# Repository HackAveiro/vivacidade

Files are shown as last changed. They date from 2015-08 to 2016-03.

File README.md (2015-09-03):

Interactive LED wall
====================
This project is being developed to be installed in a public space in Aveiro that was recovered by a wide group of public and citizens entities. [vivacidade.umnovolargo.pt!](http://vivacidade.umnovolargo.pt)  
The interactive wall has 100 LEDs mounted in jam jars ! Each bottle has an RGB LED ( Neopixel ) and LDR sensor for users to physically interact with the wall. The panel is controlled by an Arduino which uses a radio link to communicate with a gateway situated a few hundred meters away and connects the system to the Internet. Because the place has no available electricity or Internet access it's powered by solar panels.  
Users can interact with the system through the Web App: [vivacidade-ledmatrixcontroller!](https://github.com/HackAveiro/vivacidade-ledmatrixcontroller)

Prototype images
===================
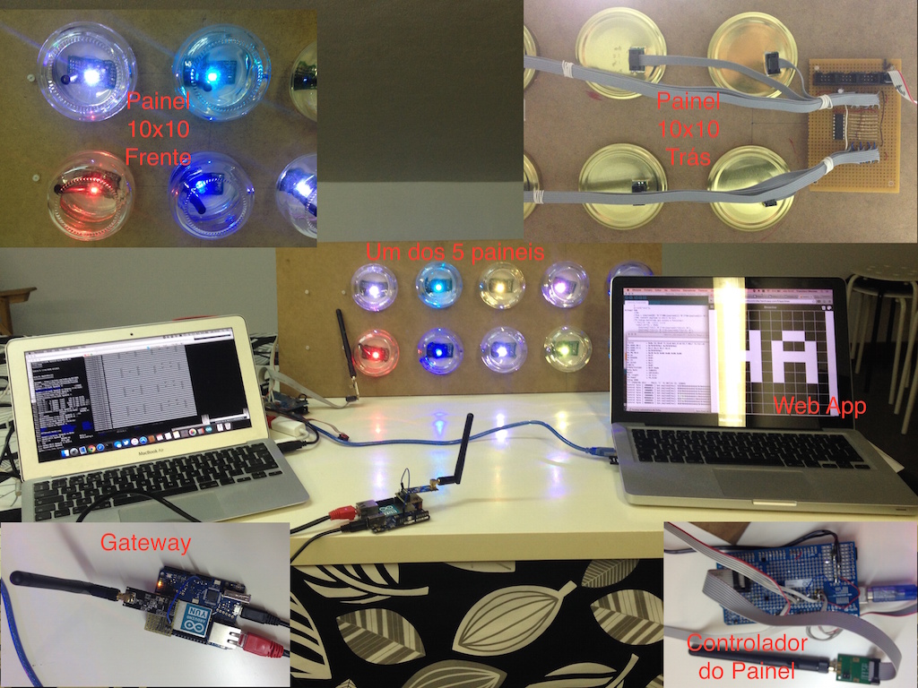
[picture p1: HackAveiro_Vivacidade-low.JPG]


GIT Structure
=============

[ADC_BOARD!](ADC_Board)
===========
The system have 10 of this boards to connect all the 100 LED. The ADC board also have ADC chips that convert the LDR light sensors readings. The ADC chips are connected to the Arduino main board via a SPI bus.
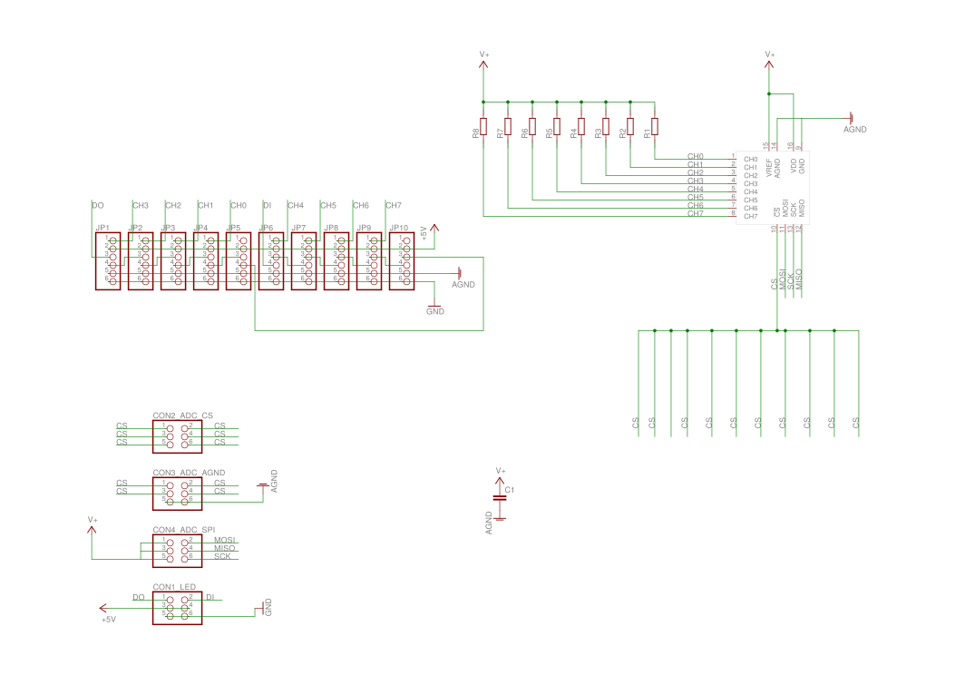
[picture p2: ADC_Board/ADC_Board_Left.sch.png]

PCB Schematic (Left Board)
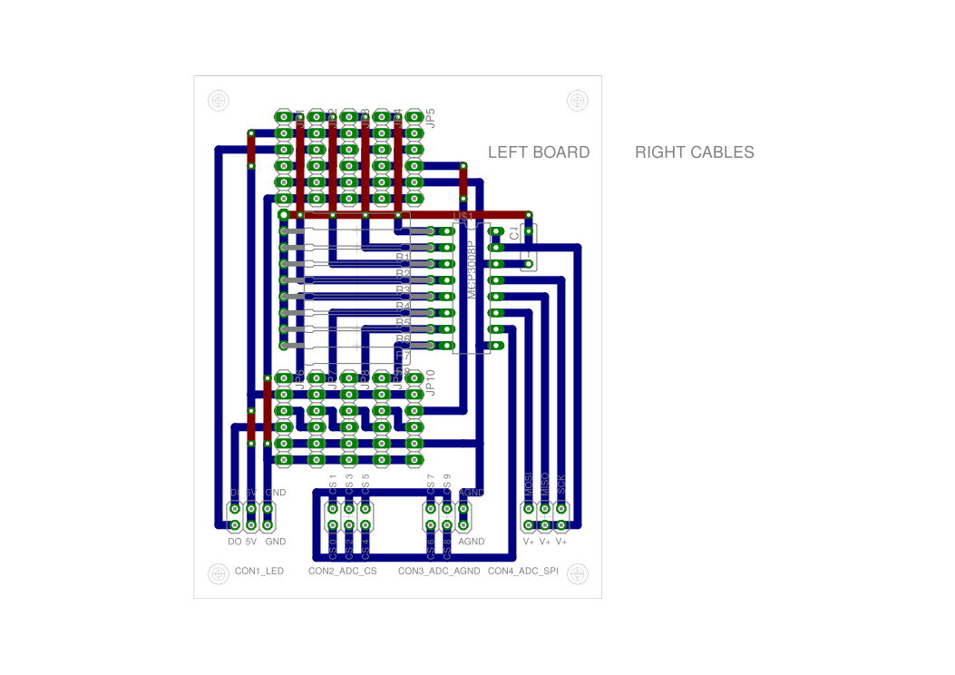
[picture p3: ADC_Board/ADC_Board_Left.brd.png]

PCB Layout ( (Left Board)
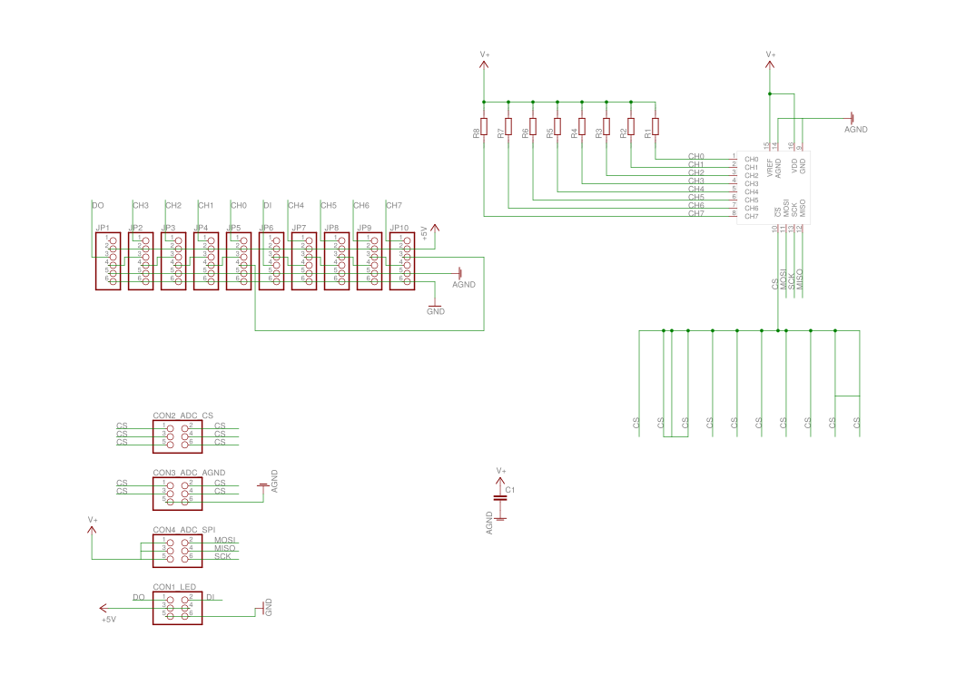
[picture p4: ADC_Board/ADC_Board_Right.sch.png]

PCB Schematic (Left Board)
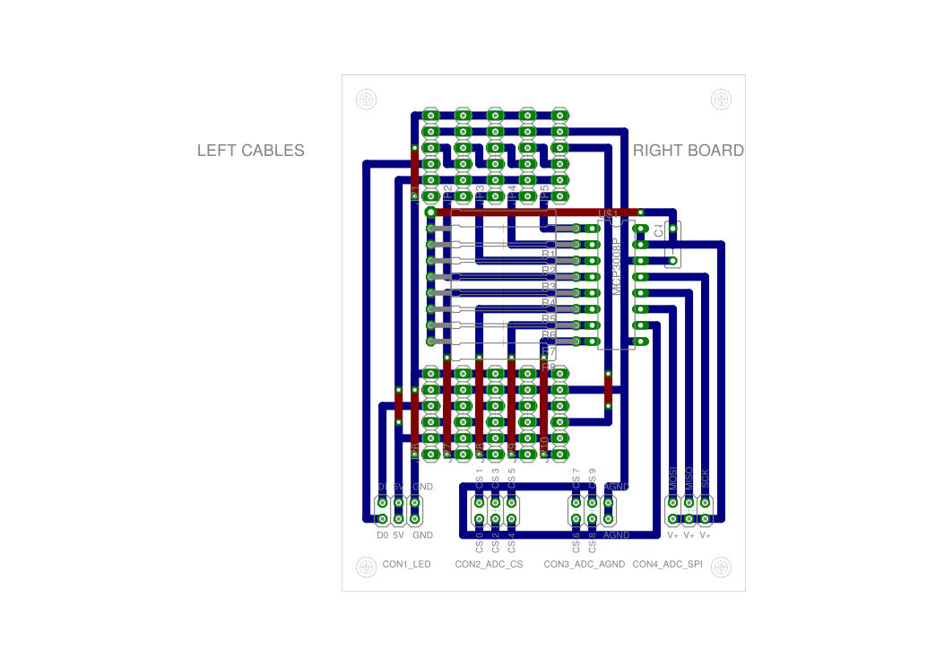
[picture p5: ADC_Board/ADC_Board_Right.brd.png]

PCB Layout ( (Left Board)

[Gateway_Vivacidade!](Gateway_Vivacidade)
==================
{{Citation needed}} 

[led_board!](led_board)
=========
{{Citation needed}} 
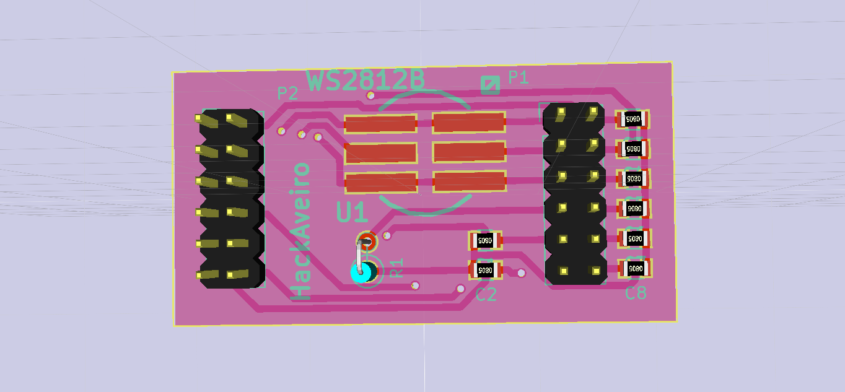
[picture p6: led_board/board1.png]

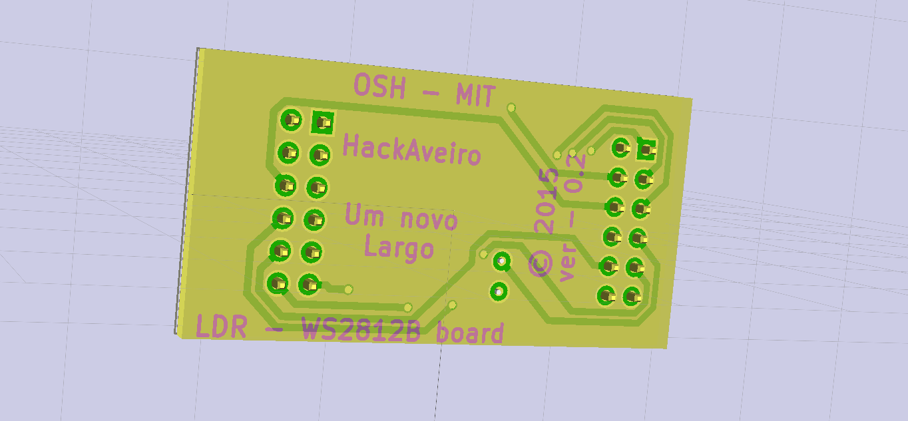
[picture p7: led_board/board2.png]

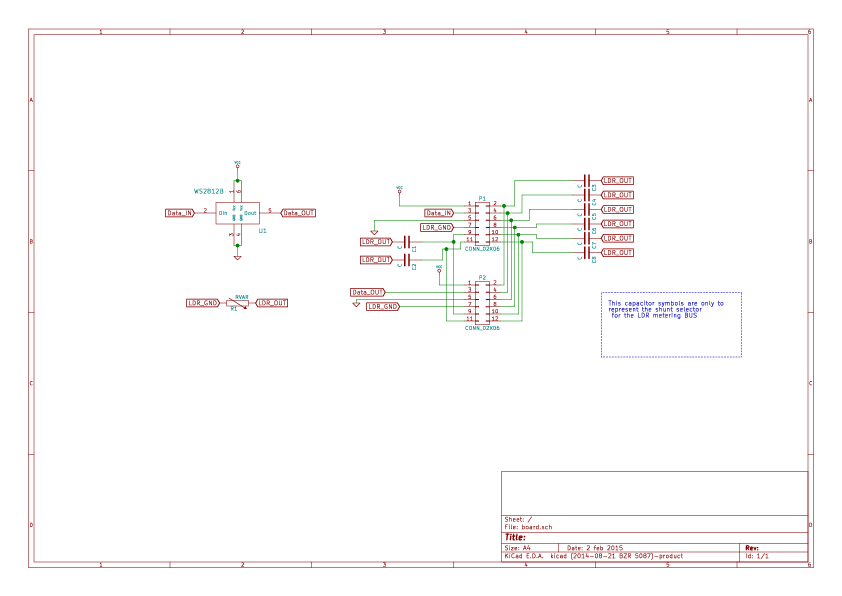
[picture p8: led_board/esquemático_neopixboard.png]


Arduino dependencies
====================
* MCP3008 - https://github.com/nodesign/MCP3008
* RF24 - https://github.com/maniacbug/RF24.git
* FastLED - https://github.com/FastLED/FastLED

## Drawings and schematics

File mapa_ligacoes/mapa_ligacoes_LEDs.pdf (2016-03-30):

# VISTA DE TRÁZ

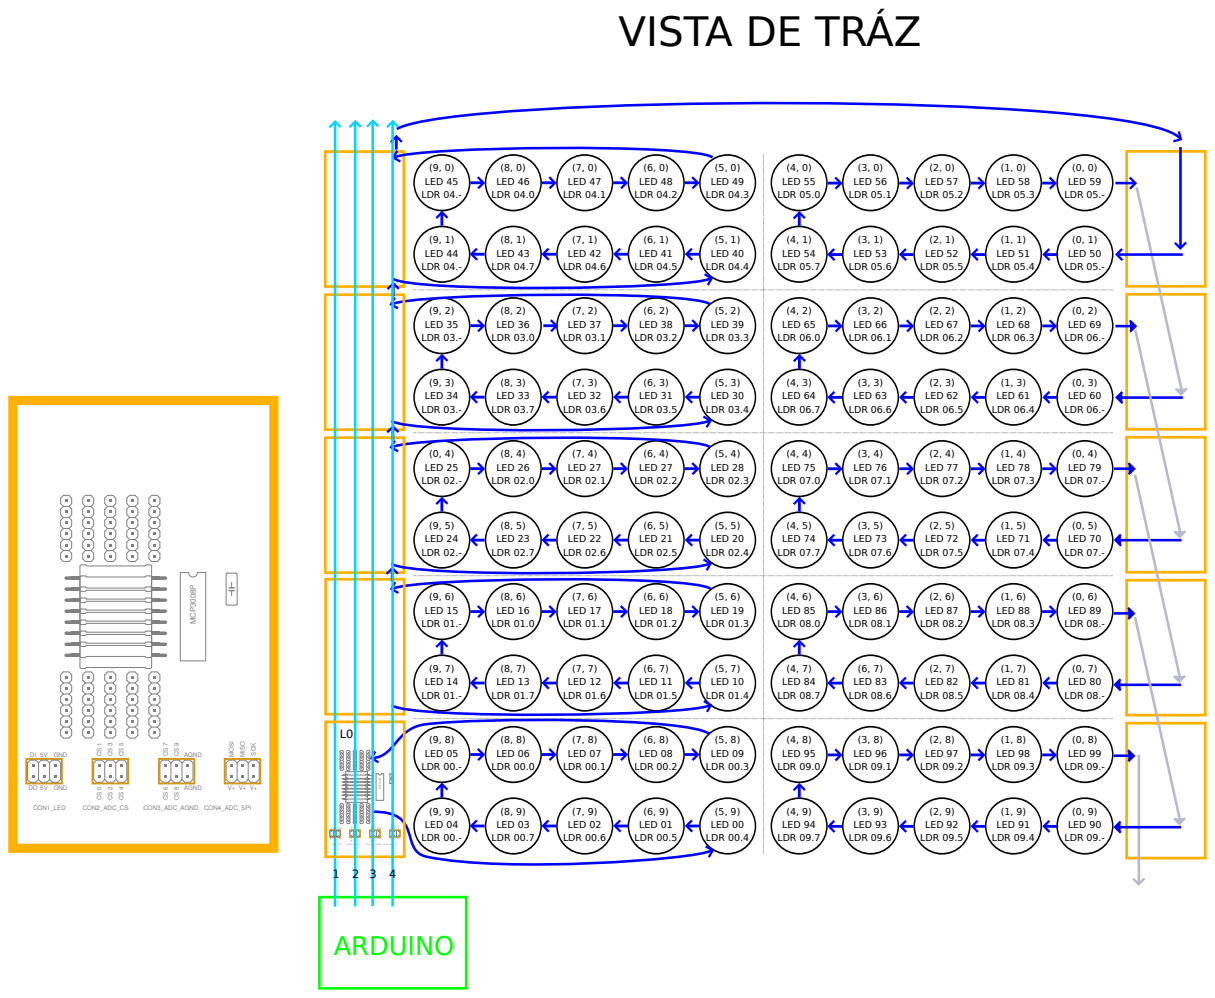
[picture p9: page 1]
(9, 9) LED 04 LDR 00.-; (0, 9) LED 90 LDR 09.-; (8, 9) LED 03 LDR 00.7; (7, 9) LED 02 LDR 00.6; (6, 9) LED 01 LDR 00.5; (5, 9) LED 00 LDR 00.4; (4, 9) LED 94 LDR 09.7; (3, 9) LED 93 LDR 09.6; (2, 9) LED 92 LDR 09.5; (1, 9) LED 91 LDR 09.4; (9, 8) LED 05 LDR 00.-; (0, 8) LED 99 LDR 09.-; (8, 8) LED 06 LDR 00.0; (7, 8) LED 07 LDR 00.1; (6, 8) LED 08 LDR 00.2; (5, 8) LED 09 LDR 00.3; (4, 8) LED 95 LDR 09.0; (3, 8) LED 96 LDR 09.1; (2, 8) LED 97 LDR 09.2; (1, 8) LED 98 LDR 09.3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

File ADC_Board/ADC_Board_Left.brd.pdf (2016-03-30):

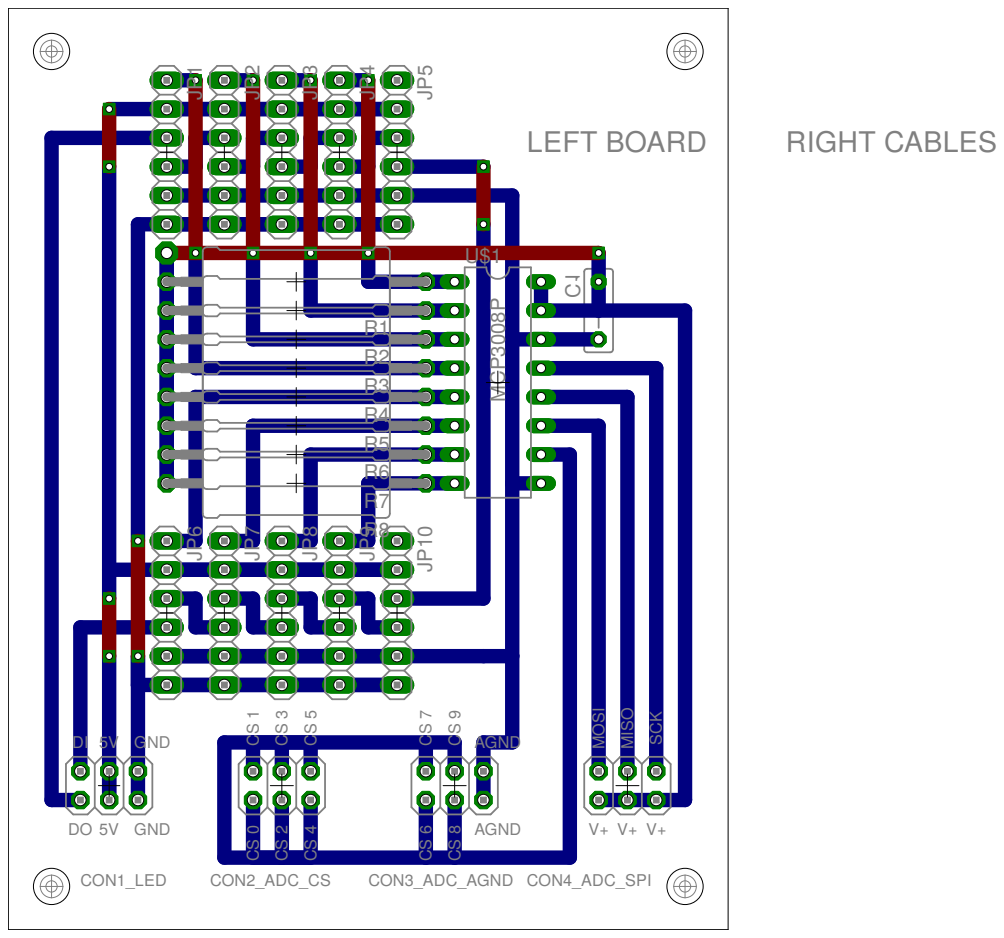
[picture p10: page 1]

C1 LEFT BOARD RIGHT CABLES

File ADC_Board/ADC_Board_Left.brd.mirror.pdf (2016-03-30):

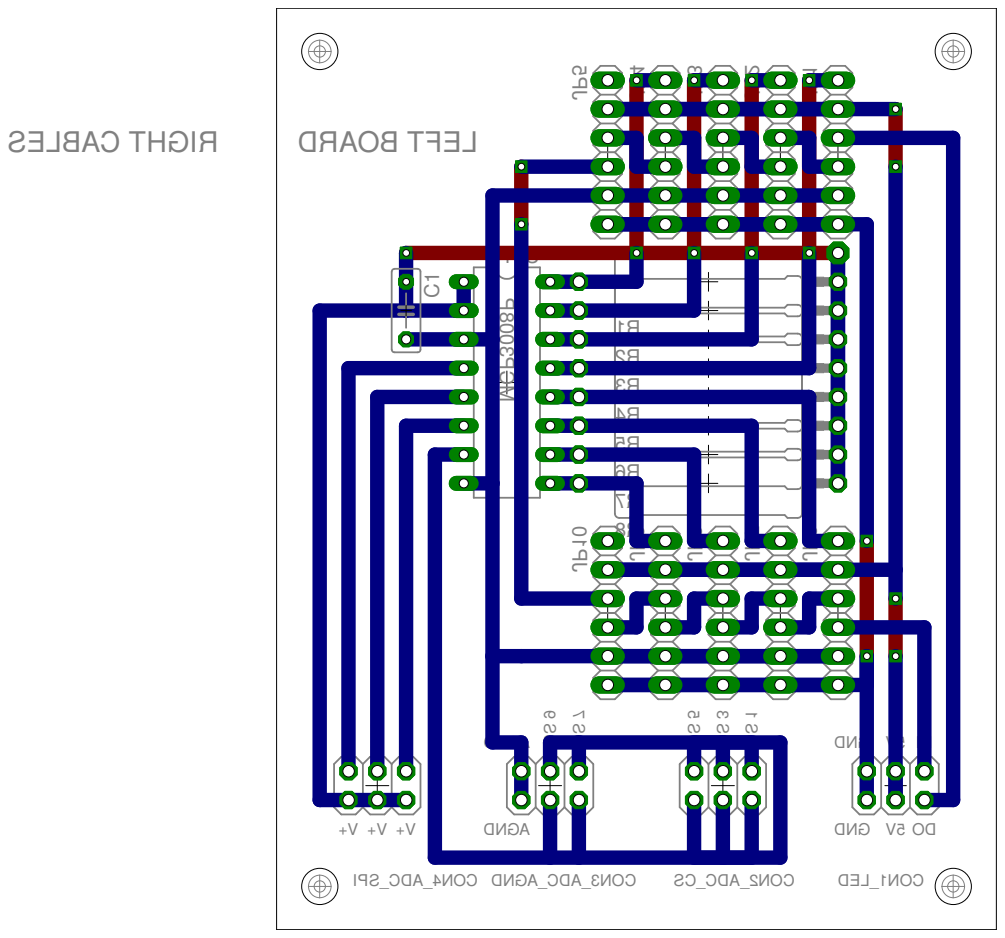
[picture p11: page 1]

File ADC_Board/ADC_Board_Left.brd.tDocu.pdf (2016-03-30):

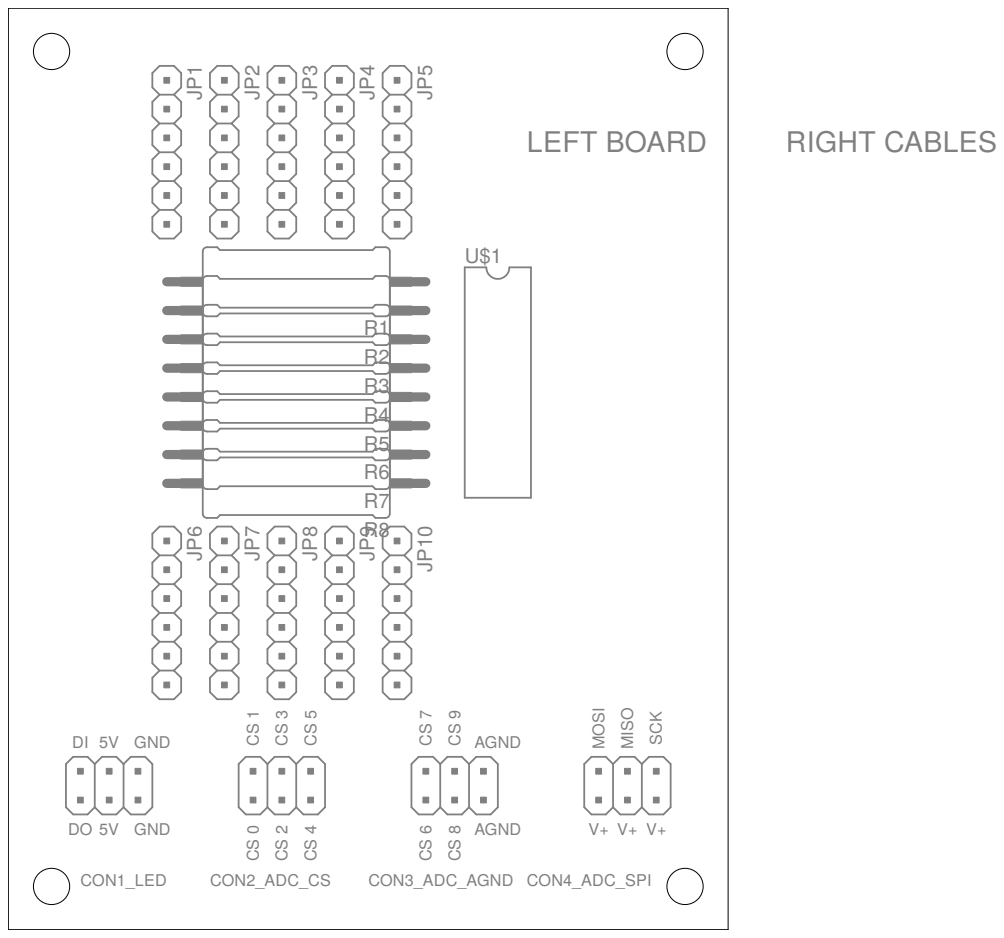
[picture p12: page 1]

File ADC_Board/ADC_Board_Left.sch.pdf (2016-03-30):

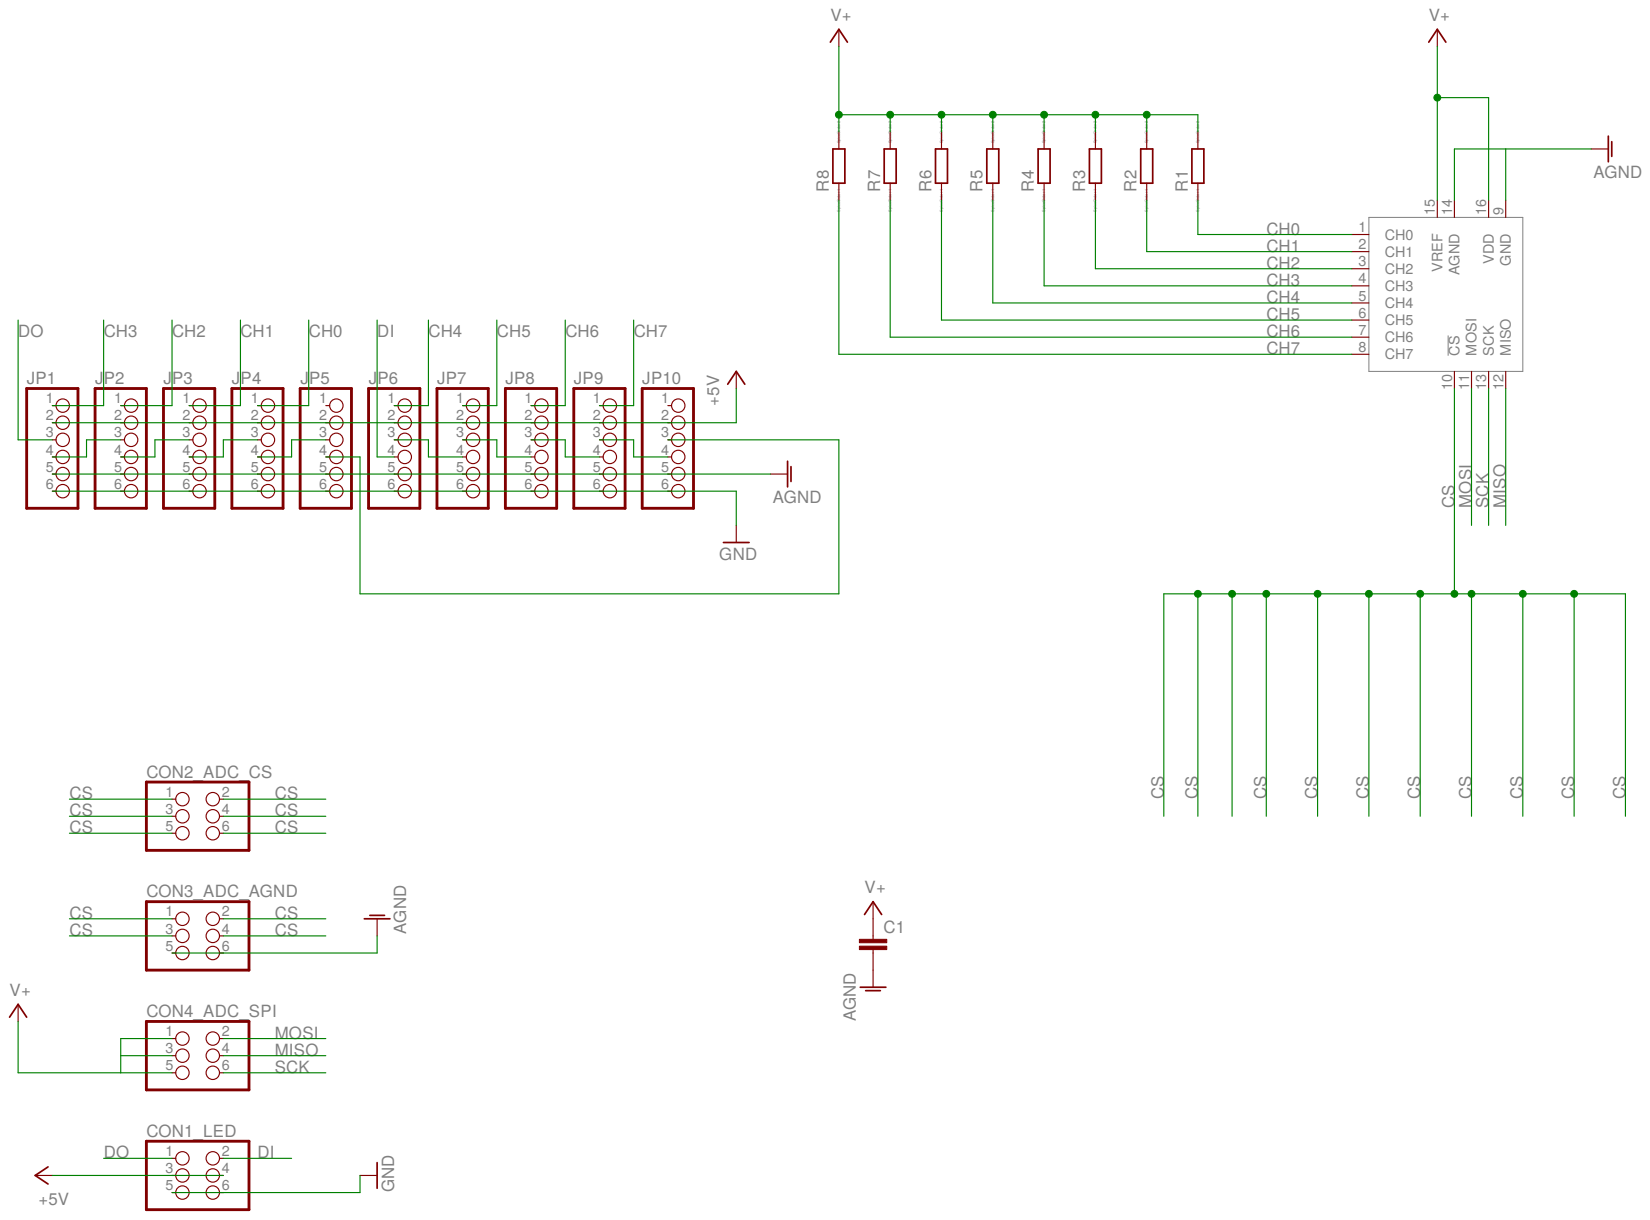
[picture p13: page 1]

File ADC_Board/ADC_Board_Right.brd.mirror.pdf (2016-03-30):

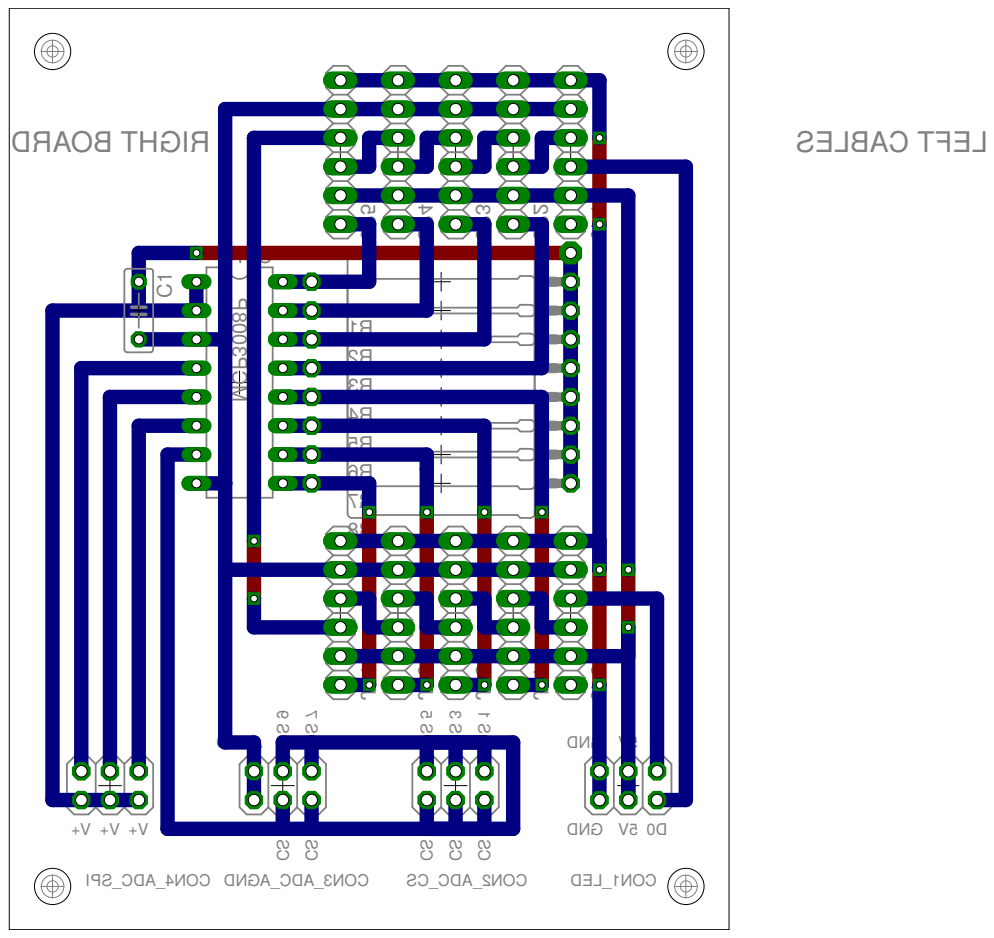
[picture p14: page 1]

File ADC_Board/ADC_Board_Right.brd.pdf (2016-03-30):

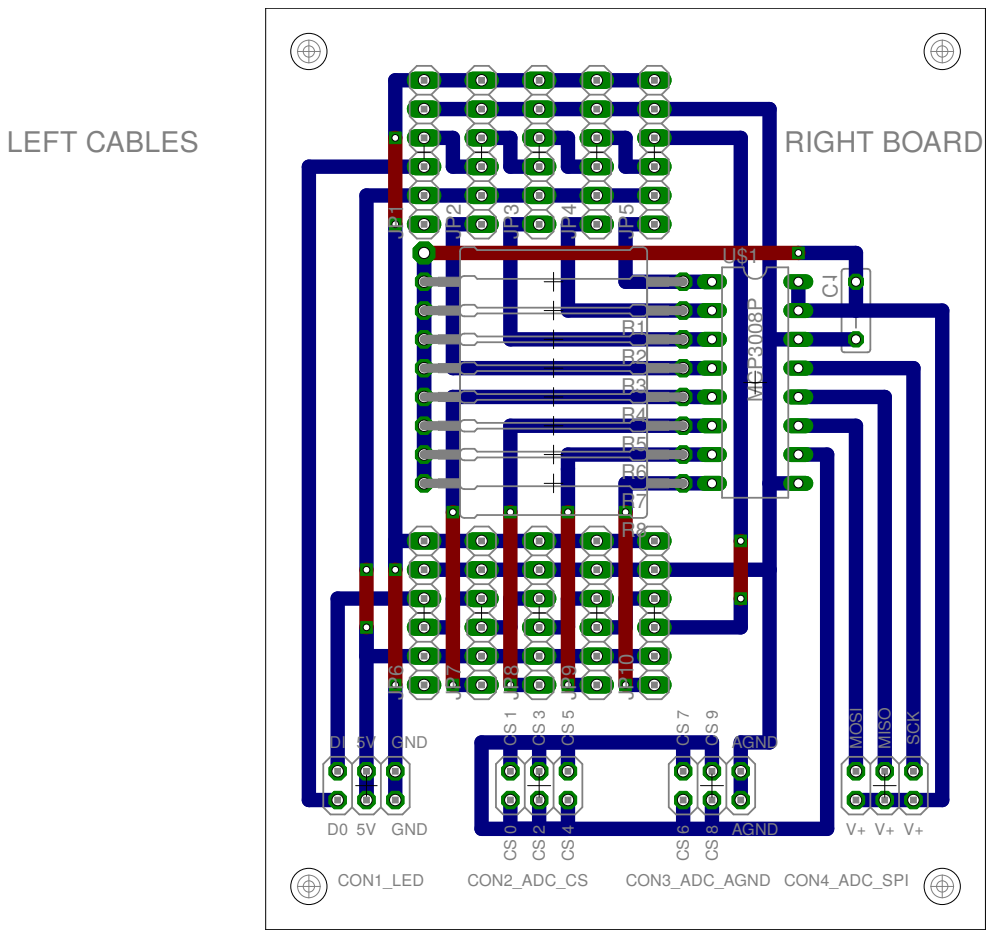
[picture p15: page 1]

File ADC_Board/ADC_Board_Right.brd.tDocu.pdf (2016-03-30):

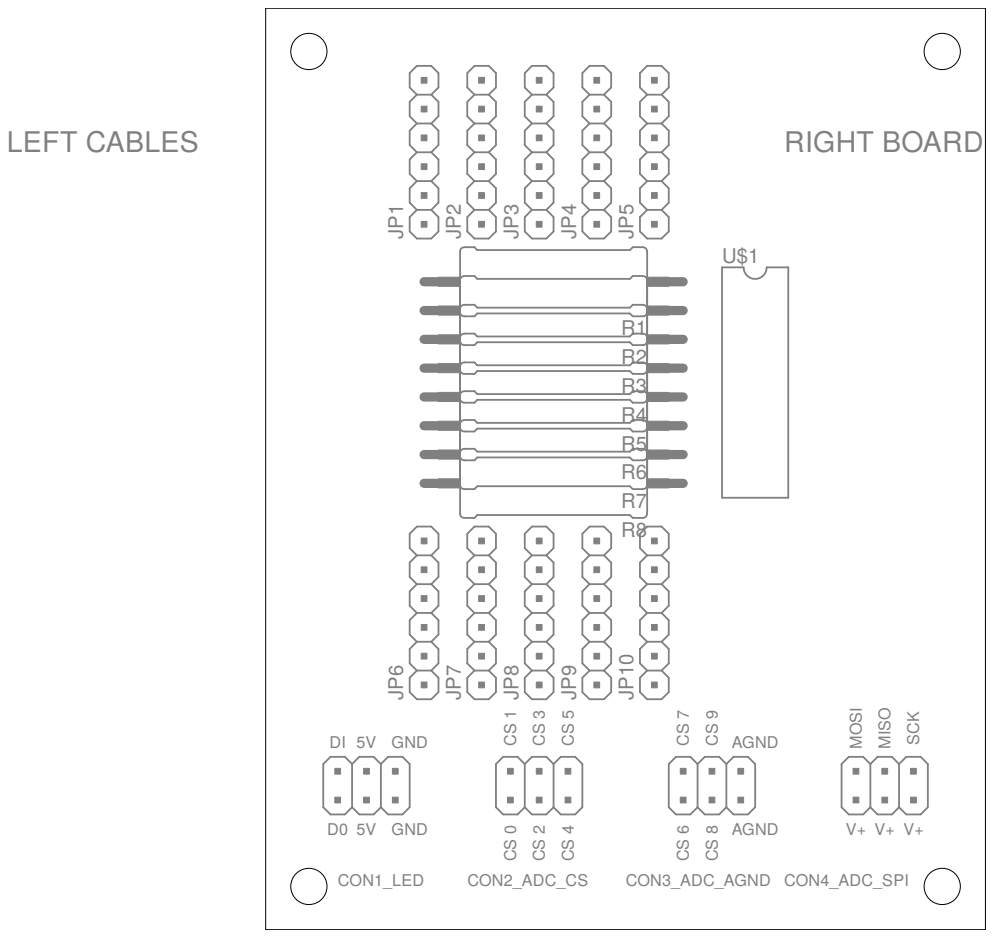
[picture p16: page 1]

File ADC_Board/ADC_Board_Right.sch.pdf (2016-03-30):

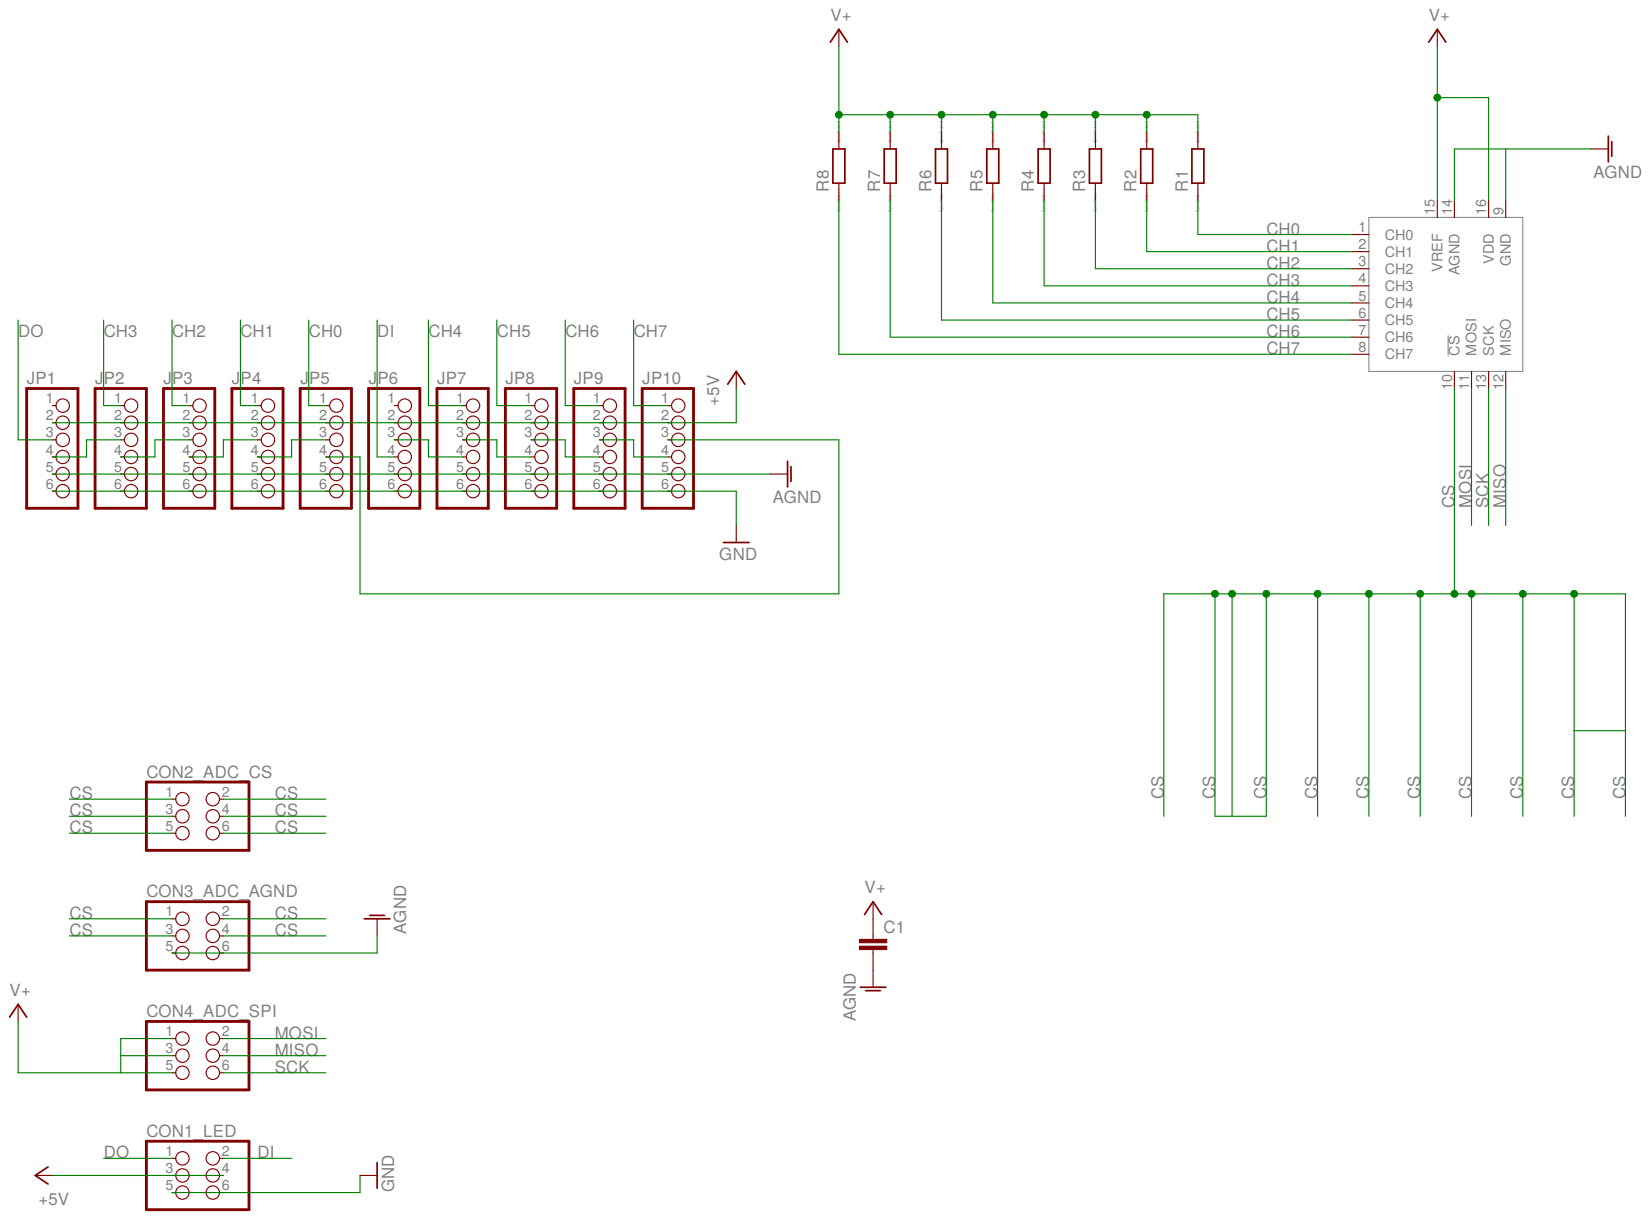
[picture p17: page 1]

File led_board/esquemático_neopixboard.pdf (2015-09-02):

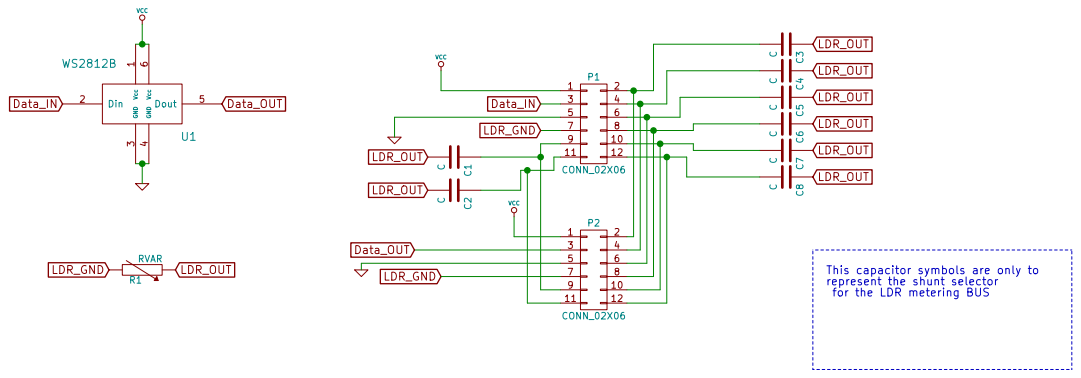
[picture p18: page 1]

represent the shunt selector

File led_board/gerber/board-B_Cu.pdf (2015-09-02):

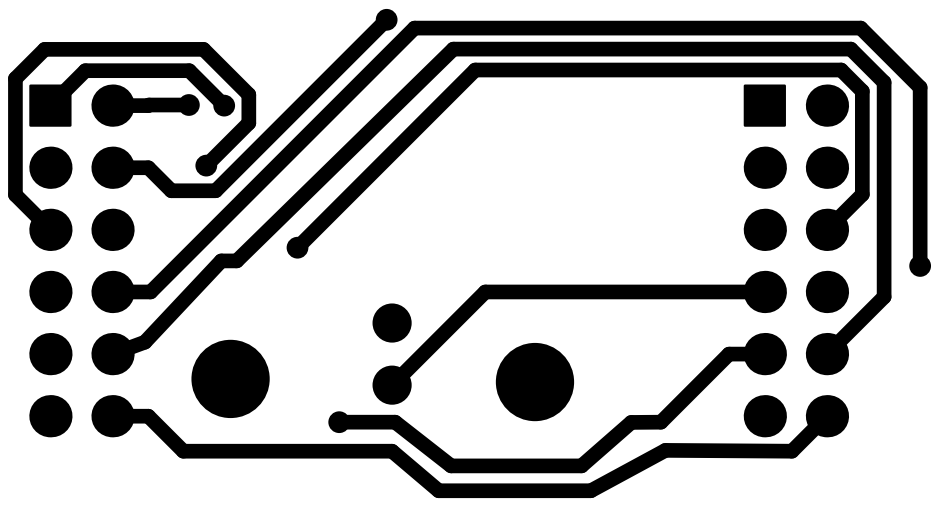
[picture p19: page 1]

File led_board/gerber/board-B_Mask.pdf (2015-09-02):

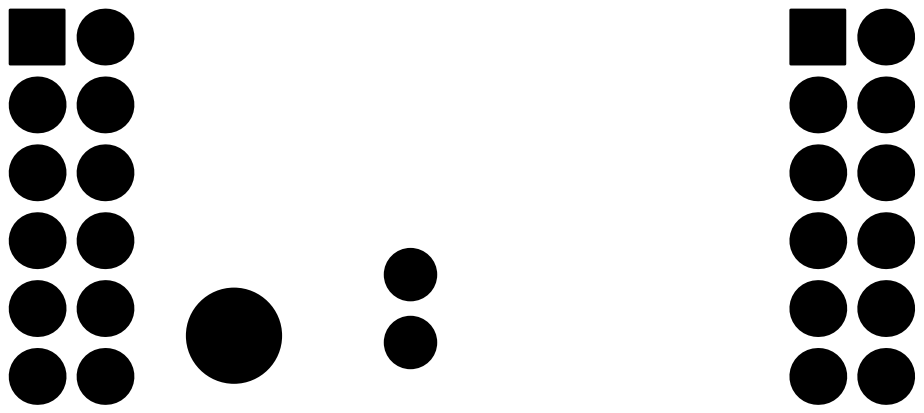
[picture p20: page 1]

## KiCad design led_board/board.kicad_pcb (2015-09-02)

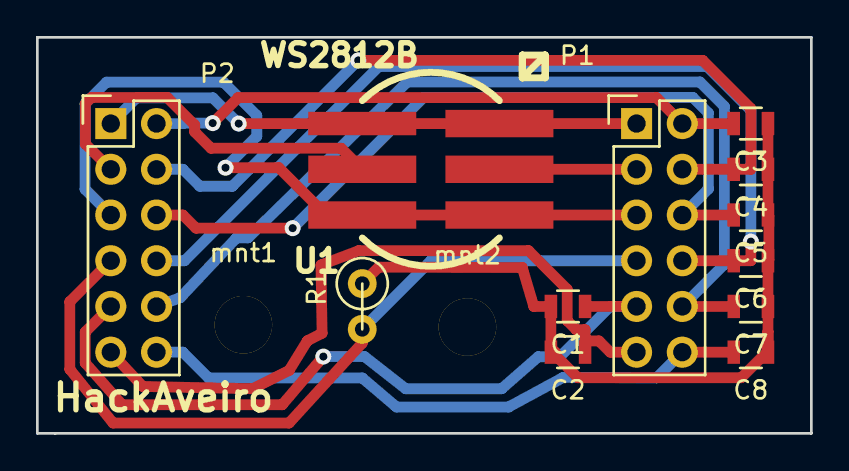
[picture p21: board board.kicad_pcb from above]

Board: 2 copper layers, 43.0 x 22.0 mm, 14 parts (0 on the bottom side), 14 nets.

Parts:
C1, C2, C3, C4, C5, C6, C7, C8: C; R_0805
P1: INPUT; Pin_Header_Straight_2x06
P2: OUTPUT; Pin_Header_Straight_2x06
R1: RVAR; R1
U1: WS2812B; u
mnt1, mnt2: MountingHole_3mm

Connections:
Data_IN: P1.3, U1.2
Data_OUT: P2.3, U1.5
GND: P1.5, P2.5, U1.3, U1.4
LDR_GND: P1.7, P2.7, R1.2
LDR_OUT: C1.2, C2.2, C3.1, C4.1, C5.1, C6.1, C7.1, C8.1, R1.1
unnamed: C1.1, P1.9, P2.9
unnamed: C2.1, P1.11, P2.11
unnamed: C3.2, P1.2, P2.2
unnamed: C4.2, P1.4, P2.4
unnamed: C5.2, P1.6, P2.6
unnamed: C6.2, P1.8, P2.8
unnamed: C7.2, P1.10, P2.10
unnamed: C8.2, P1.12, P2.12
VCC: P1.1, P2.1, U1.1, U1.6

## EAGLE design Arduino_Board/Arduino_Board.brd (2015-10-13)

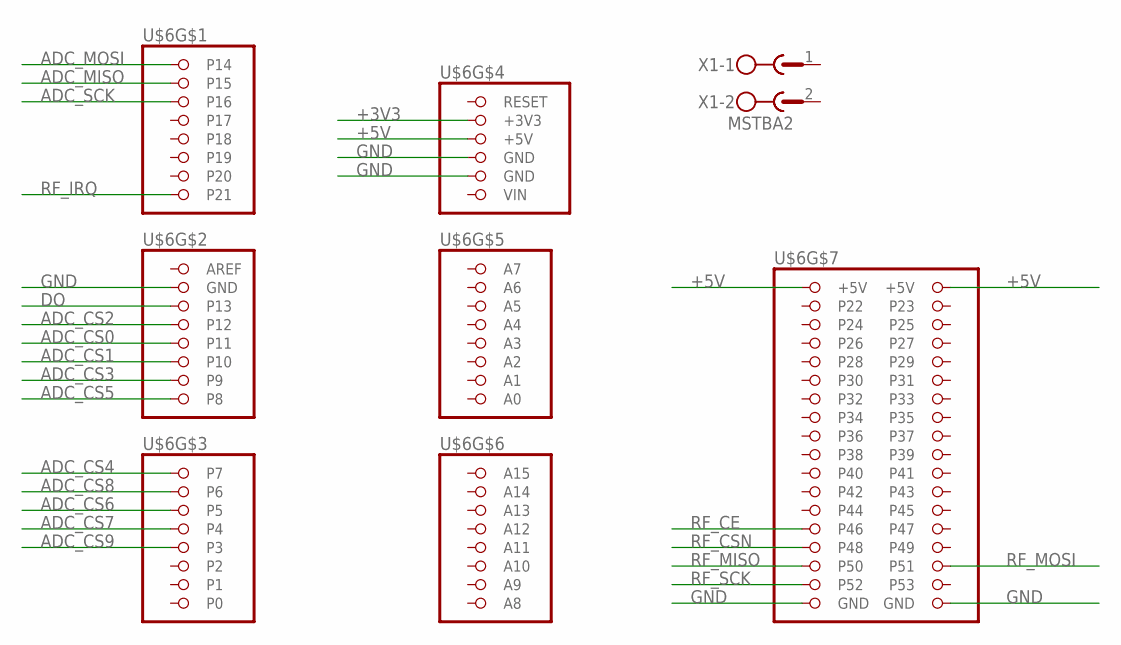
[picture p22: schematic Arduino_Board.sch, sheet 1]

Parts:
U$6: ARDUINO_MEGA
X1: MSTBA2

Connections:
+3V3: U$6.+3V3; also elsewhere on the board
+5V: U$6.+5V@1 (+5V), U$6.+5V@2 (+5V), U$6.+5V@3 (+5V); also elsewhere on the board
ADC_CS0: U$6.P11; also elsewhere on the board
ADC_CS1: U$6.P10; also elsewhere on the board
ADC_CS2: U$6.P12; also elsewhere on the board
ADC_CS3: U$6.P9; also elsewhere on the board
ADC_CS4: U$6.P7; also elsewhere on the board
ADC_CS5: U$6.P8; also elsewhere on the board
ADC_CS6: U$6.P5; also elsewhere on the board
ADC_CS7: U$6.P4; also elsewhere on the board
ADC_CS8: U$6.P6; also elsewhere on the board
ADC_CS9: U$6.P3; also elsewhere on the board
ADC_MISO: U$6.P15; also elsewhere on the board
ADC_MOSI: U$6.P14; also elsewhere on the board
ADC_SCK: U$6.P16; also elsewhere on the board
DO: U$6.P13; also elsewhere on the board
GND: U$6.GND@1 (GND), U$6.GND@2 (GND), U$6.GND@3 (GND), U$6.GND@4 (GND), U$6.GND@5 (GND); also elsewhere on the board
RF_CE: U$6.P46; also elsewhere on the board
RF_CSN: U$6.P48; also elsewhere on the board
RF_IRQ: U$6.P21; also elsewhere on the board
RF_MISO: U$6.P50; also elsewhere on the board
RF_MOSI: U$6.P51; also elsewhere on the board
RF_SCK: U$6.P52; also elsewhere on the board

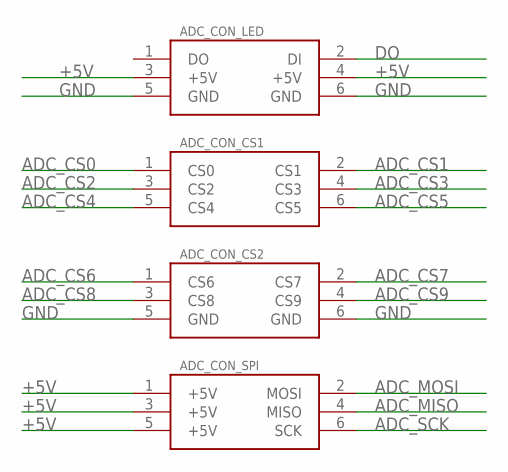
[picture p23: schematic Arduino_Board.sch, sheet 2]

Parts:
U$2: ADC_CON_LED; T821_2X03
U$3: ADC_CON_CS1; T821_2X03
U$4: ADC_CON_CS2; T821_2X03
U$5: ADC_CON_SPI; T821_2X03

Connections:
+5V: U$2.3 (+5V), U$2.4 (+5V), U$5.1 (+5V), U$5.3 (+5V), U$5.5 (+5V); also elsewhere on the board
ADC_CS0: U$3.1 (CS0); also elsewhere on the board
ADC_CS1: U$3.2 (CS1); also elsewhere on the board
ADC_CS2: U$3.3 (CS2); also elsewhere on the board
ADC_CS3: U$3.4 (CS3); also elsewhere on the board
ADC_CS4: U$3.5 (CS4); also elsewhere on the board
ADC_CS5: U$3.6 (CS5); also elsewhere on the board
ADC_CS6: U$4.1 (CS6); also elsewhere on the board
ADC_CS7: U$4.2 (CS7); also elsewhere on the board
ADC_CS8: U$4.3 (CS8); also elsewhere on the board
ADC_CS9: U$4.4 (CS9); also elsewhere on the board
ADC_MISO: U$5.4 (MISO); also elsewhere on the board
ADC_MOSI: U$5.2 (MOSI); also elsewhere on the board
ADC_SCK: U$5.6 (SCK); also elsewhere on the board
DO: U$2.2 (DI); also elsewhere on the board
GND: U$2.5 (GND), U$2.6 (GND), U$4.5 (GND), U$4.6 (GND); also elsewhere on the board

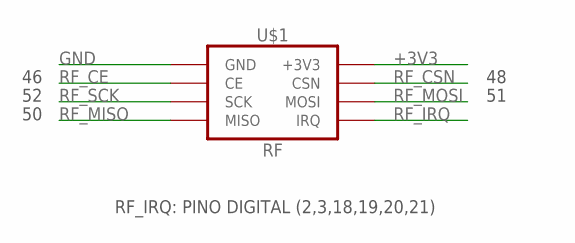
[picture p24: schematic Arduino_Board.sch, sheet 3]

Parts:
U$1: RF

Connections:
+3V3: U$1.2 (+3V3); also elsewhere on the board
GND: U$1.1 (GND); also elsewhere on the board
RF_CE: U$1.3 (CE); also elsewhere on the board
RF_CSN: U$1.4 (CSN); also elsewhere on the board
RF_IRQ: U$1.8 (IRQ); also elsewhere on the board
RF_MISO: U$1.7 (MISO); also elsewhere on the board
RF_MOSI: U$1.6 (MOSI); also elsewhere on the board
RF_SCK: U$1.5 (SCK); also elsewhere on the board

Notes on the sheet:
RF_IRQ: PINO DIGITAL (2,3,18,19,20,21)

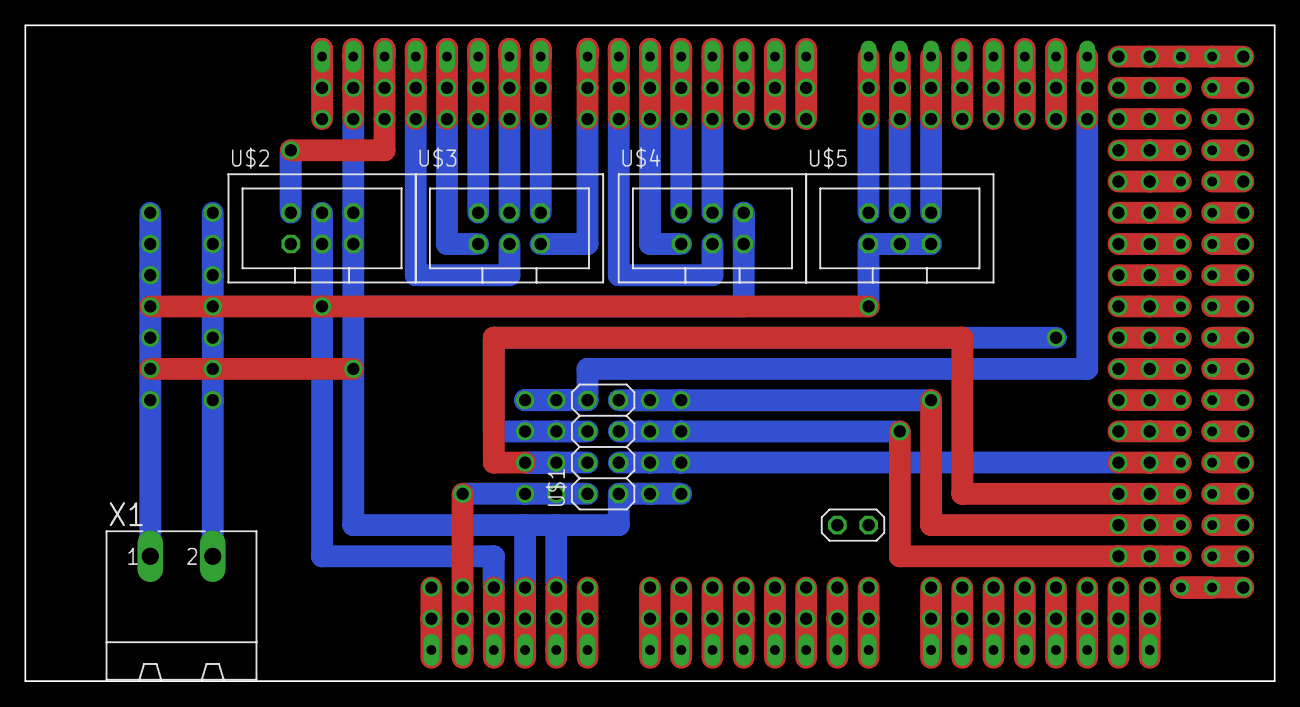
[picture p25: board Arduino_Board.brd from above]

Board: 2 copper layers, 101.6 x 53.3 mm, 7 parts (0 on the bottom side), 23 nets.

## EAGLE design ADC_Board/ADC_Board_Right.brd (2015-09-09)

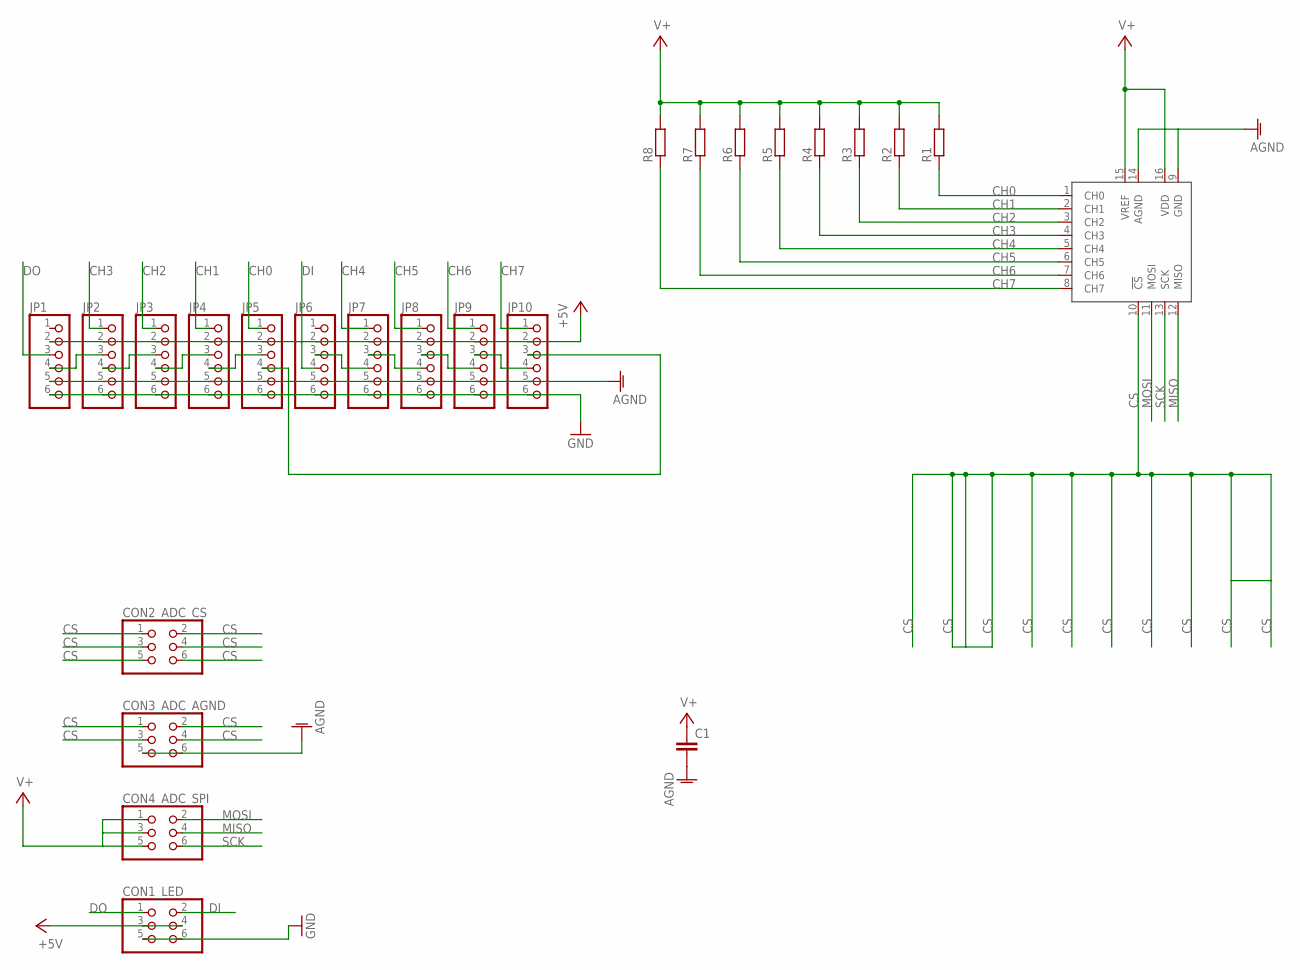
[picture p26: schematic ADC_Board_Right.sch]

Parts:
C1: C-EU050-025X075; C050-025X075
CON1_LED, CON2_ADC_CS, CON3_ADC_AGND, CON4_ADC_SPI: PINHD-2X3; 2X03
JP1, JP2, JP3, JP4, JP5, JP6, JP7, JP8, JP9, JP10: PINHD-1X6; 1X06
R1, R2, R3, R4, R5, R6, R7, R8: R-EU_0617_22; 0617/22
U$1: MCP3008P; DIL16

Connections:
+5V: CON1_LED.3, CON1_LED.4, JP1.2, JP2.2, JP3.2, JP4.2, JP5.2, JP6.2, JP7.2, JP8.2, JP9.2, JP10.2
AGND: C1.2, CON3_ADC_AGND.5, CON3_ADC_AGND.6, JP1.5, JP2.5, JP3.5, JP4.5, JP5.5, JP6.5, JP7.5, JP8.5, JP9.5, JP10.5, U$1.9 (GND), U$1.14 (AGND)
CH0: JP5.1, R1.1, U$1.1 (CH0)
CH1: JP4.1, R2.1, U$1.2 (CH1)
CH2: JP3.1, R3.1, U$1.3 (CH2)
CH3: JP2.1, R4.1, U$1.4 (CH3)
CH4: JP7.1, R5.1, U$1.5 (CH4)
CH5: JP8.1, R6.1, U$1.6 (CH5)
CH6: JP9.1, R7.1, U$1.7 (CH6)
CH7: JP10.1, R8.1, U$1.8 (CH7)
CS: CON2_ADC_CS.1, CON2_ADC_CS.2, CON2_ADC_CS.3, CON2_ADC_CS.4, CON2_ADC_CS.5, CON2_ADC_CS.6, CON3_ADC_AGND.1, CON3_ADC_AGND.2, CON3_ADC_AGND.3, CON3_ADC_AGND.4, U$1.10 (!CS)
DI: CON1_LED.2, JP6.4
DO: CON1_LED.1, JP1.3
GND: CON1_LED.5, CON1_LED.6, JP1.6, JP2.6, JP3.6, JP4.6, JP5.6, JP6.6, JP7.6, JP8.6, JP9.6, JP10.6
MISO: CON4_ADC_SPI.4, U$1.12 (MISO)
MOSI: CON4_ADC_SPI.2, U$1.11 (MOSI)
unnamed: JP6.3, JP7.4
unnamed: JP1.4, JP2.3
unnamed: JP2.4, JP3.3
unnamed: JP3.4, JP4.3
unnamed: JP4.4, JP5.3
unnamed: JP5.4, JP10.3
unnamed: JP7.3, JP8.4
unnamed: JP8.3, JP9.4
unnamed: JP9.3, JP10.4
SCK: CON4_ADC_SPI.6, U$1.13 (SCK)
V+: C1.1, CON4_ADC_SPI.1, CON4_ADC_SPI.3, CON4_ADC_SPI.5, R1.2, R2.2, R3.2, R4.2, R5.2, R6.2, R7.2, R8.2, U$1.15 (VREF), U$1.16 (VDD)

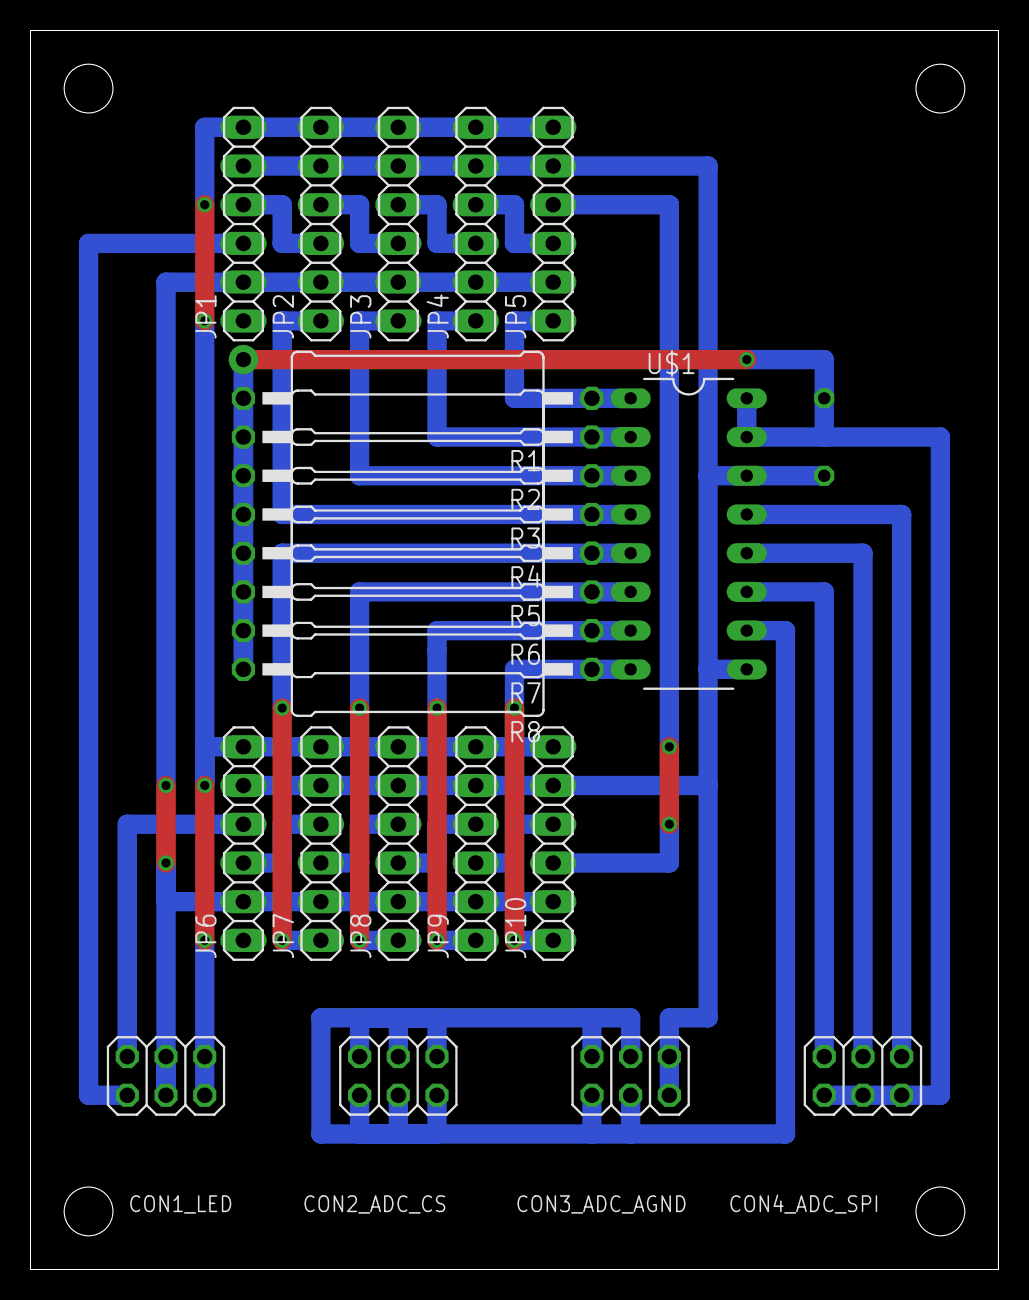
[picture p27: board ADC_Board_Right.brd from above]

Board: 2 copper layers, 63.5 x 81.3 mm, 24 parts (1 on the bottom side), 27 nets.

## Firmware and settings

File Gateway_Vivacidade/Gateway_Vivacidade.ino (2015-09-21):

//#define GATEWAY

#ifdef GATEWAY
#include <Bridge.h>
#include <YunClient.h>          
#include <PubSubClient.h>
#endif

#include <SPI.h>
#include <RF24.h>
#include "printf.h"
#include "FastLED.h"

const uint64_t pipes[2] = { 0xF0F0F0F0E1LL, 0xF0F0F0F0D2LL };

// Set up nRF24L01 radio on SPI bus plus pins 3 & 4
#ifdef GATEWAY
RF24 radio(3, 4);
#else
RF24 radio(46, 48);
#endif

// NeoPixel Communication
#define BUFFER_SIZE 32      //its actually RF24 Max Packet Size
unsigned char packet[BUFFER_SIZE] = {0};

#define MQTT_CLIENT_ID  "HackAveiro.org"
#define MQTT_SERVER     "broker.mqtt-dashboard.com"
#define MQTT_TOPIC      "/hackaveiro/bitmap"
String mqttString = "";

// Role
// The various roles supported by this sketch
typedef enum { role_listener = 1, role_sender } role_e;
const char* role_friendly_name[] = { "invalid", "Listener", "Sender"};

role_e role = role_listener;

#ifdef GATEWAY
YunClient yun;
PubSubClient client(MQTT_SERVER, 1883, callback, yun);
#endif

// How many leds in your strip?1
#define NUM_LED_LINES 10
#define NUM_LED_COLUMNS 10
#define NUM_LEDS (NUM_LED_LINES * NUM_LED_COLUMNS)
#define DATA_PIN 2
// Define the array of leds
CRGB leds[NUM_LEDS];

//Lookup table that maps leds position to "real" led position
char ledmap[NUM_LEDS] = {
  59, 58, 57, 56, 55,  49, 48, 47, 46, 45,
  50, 51, 52, 53, 54,  40, 41, 42, 43, 44,
  69, 68, 67, 66, 65,  39, 38, 37, 36, 35,
  60, 61, 62, 63, 64,  30, 31, 32, 33, 34,
  79, 78, 77, 76, 75,  29, 28, 27, 26, 25,
  70, 71, 72, 73, 74,  20, 21, 22, 23, 24,
  89, 88, 87, 86, 85,  19, 18, 17, 16, 15,
  80, 81, 82, 83, 84,  10, 11, 12, 13, 14,
  99, 98, 97, 96, 95,  9, 8, 7, 6, 5,
  90, 91, 92, 93, 94,  0, 1, 2, 3, 4
};

//59, 58, 57, 56, 55, 50, 51, 52, 53, 54, 0, 1, 2, 3, 4, 5, 6, 7, 8, 9, 10, 11, 12, 13, 14, 15, 16, 17, 18, 19, 20, 21, 22, 23, 24, 25, 26, 27, 28, 29, 30, 31, 32, 33, 34, 35, 36, 37, 38, 39, 40, 41, 42, 43, 44, 45, 46, 47, 48, 49, 60, 61, 62, 63, 64, 65, 66, 67, 68, 69, 70, 71, 72, 73, 74, 75, 76, 77, 78, 79, 80, 81, 82, 83, 84, 85, 86, 87, 88, 89, 90, 91, 92, 93, 94, 95, 96, 97, 98, 99
// MQTT Callback function
void callback(char* topic, byte* payload, unsigned int length) {
  printf("MQTT bitmat(%d)", length);
  for (int i = 0; i < length; i++) {
    mqttString += (char) payload[i];
    if (payload[i] == 'Q') return;
  }
  Serial.println(mqttString);

  role = role_sender;
}

// Debug Function
void print_packet_bitmap(unsigned char *packet, size_t size) {
  unsigned char cb = packet[0];
  printf("Control Byte [ ");
  for ( int i = 0; i < 8; i++) {
    if (cb & 0x80)
      printf("1");
    else
      printf("0");

    cb <<= 1;
  }
  printf(" ] Line:%d - ", (unsigned int) (packet[0] & 0x7F));
  for (int i = 1; i < size; i++) {
    printf("%02X", (unsigned char) packet[i]);
    if ( i % 3 == 0)
      printf(" ");
  }
  printf("\r\n");
}

void setup() {

  Serial.begin(115200);
#ifdef GATEWAY //This is actually because we have a YUN
  if  (!Serial) {
    delay(5000);
  }
#endif

  printf_begin();
  Serial.println("Setup BEGIN");

  /* SETUP RADIO */
  radio.begin();
  // enable dynamic payloads
  radio.enableDynamicPayloads();
  // optionally, increase the delay between retries & # of retries
  radio.setRetries(15, 15);
  radio.setAutoAck(true);
  radio.setDataRate(RF24_250KBPS);
  //radio.setChannel(1);
  radio.setPALevel(RF24_PA_MAX);

  radio.openWritingPipe(pipes[0]);
  radio.openReadingPipe(1, pipes[1]);

  radio.startListening();
  radio.printDetails();
  /* DONE RADIO SETUP */

#ifdef GATEWAY
  Serial.println("GATEWAY Version");
  Bridge.begin();

  if (client.connect(MQTT_CLIENT_ID)) {
    Serial.println("connected");
    client.subscribe(MQTT_TOPIC);
  }
#else
  Serial.println("DISPLAY Version");
  FastLED.addLeds<NEOPIXEL, DATA_PIN>(leds, NUM_LEDS);
#endif

  Serial.println("Setup DONE");
}

void loop() {
#ifdef GATEWAY
  client.loop();

  if (!client.connected()) {
    delay(2000);
    client.connect(MQTT_CLIENT_ID);
    Serial.println("Reconnected");
    client.subscribe(MQTT_TOPIC);
  }
#endif

  if (role == role_listener) {
    if (radio.available() ) {
      size_t len = radio.getDynamicPayloadSize();
      if (radio.read( &packet, len ) == false)
        return; //Can't read packet? Abort!

      print_packet_bitmap(packet, BUFFER_SIZE);
      if ((packet[0] & 0x80) == 0x80) {     //first bit indicates that the packet contains a bitmap
        int line = packet[0] & 0x7F;    //line number

        //if (line > 1) return; //TODO ISTO È TESTE!!!!
        Serial.println("display!");
        //Payload in binary: CB(1B);R1G1B1(3B);R2G2B2(3B); ... ; R10G10B10(3B). Total = ...
        unsigned pixel = 0;
        for (int i = 1; i < len; i += 3) { //we start in byte 1 (payload)
          leds[ledmap[line * NUM_LED_COLUMNS + pixel]] = CRGB(
                (unsigned char)packet[i],
                (unsigned char)packet[i + 1],
                (unsigned char)packet[i + 2]
              );
          pixel++;
        }

#ifndef GATEWAY
        //TODO A verdade é que o array leds não pode ser enviado directamente devido a maneira que construimos o painel...
        //TODO vivacidadeLeds = convert(leds);
        FastLED.show();                     //Send bit stream to NEOPIXELS stripe
#endif
      } else if (packet[0] & 0x80 == 0x00) {
        //TODO packet contains the readings from the LDR's
      }
      // Delay just a little bit to let the other unit
      // make the transition to receiver
      delay(20);
    }
  } else if ( role == role_sender && (mqttString.length() != 0) ) {

    // Initialize Control Byte
    unsigned char *control_byte = packet;
    (*control_byte) = mqttString.substring(0, 1).toInt(); // write line number
    (*control_byte) = (*control_byte) | 0x80;   // set first bit as a flag indicating bitmap packet

    //convert the remaining string to binary and save it in payload
    int r = 1;  //mqttString index
    int p = 1;  //payload index
    while (r < mqttString.length() && p < BUFFER_SIZE) {
      char color[2] = {mqttString[r], mqttString[r + 1]}; //create a string with each 2 chars
      packet[p] = (unsigned char) (strtol(color, NULL, 16));  //convert to unsigned char
      r += 2;
      p++;
    }

    // First, stop listening so we can talk.
    radio.stopListening();
    bool ok = radio.write(&packet, BUFFER_SIZE);
    if (ok) {
      print_packet_bitmap(packet, BUFFER_SIZE);
    } else {
      printf("failed to send.\n\r");
    }
    // Now, continue listening
    radio.startListening();
    // Clear mqttString
    mqttString = "";
  }
  //TODO read LDR's and send it periodically (carefully not to enter a state where we always send LDR and never enter listener role

  role = role_listener;
}

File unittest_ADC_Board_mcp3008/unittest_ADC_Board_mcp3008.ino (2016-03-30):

#include "MCP3008.h"

// Define the array of leds
// (CLK, MOSI, MISO, CS)
  MCP3008 mcp3008(16, 14, 15, 11); // CS0
//MCP3008 mcp3008(16, 14, 15, 10); // CS1
//MCP3008 mcp3008(16, 14, 15, 12); // CS2
//MCP3008 mcp3008(16, 14, 15,  9); // CS3
//MCP3008 mcp3008(16, 14, 15,  7); // CS4
//MCP3008 mcp3008(16, 14, 15,  8); // CS5
//MCP3008 mcp3008(16, 14, 15,  5); // CS6
//MCP3008 mcp3008(16, 14, 15,  4); // CS7
//MCP3008 mcp3008(16, 14, 15,  6); // CS8
//MCP3008 mcp3008(16, 14, 15,  3); // CS9

void setup()
{
  Serial.begin(115200);

  Serial.println("Setup BEGIN");

  Serial.println("Setup DONE");
}

void loop()
{
  int i;
  
  for(i=0; i <8; ++i)
  {
    int v = mcp3008.readADC(i);
    
    Serial.print("\t");  
    Serial.print(v);
  }
  
  Serial.println();
  
}

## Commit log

2015-07-08 Teste Matriz de 10 LED
    This code was tested with a 10 LED matrix.
    Protocol: RGB; HEX; ASCII; 6B x 10LED transmited
2015-08-19 Imagem
    Imagem criada para a submissão à MakerFaire.
2015-09-02 Adicionado esquema eléctrico das placas das ADCs
    [ADC_Board_Left.brd, ADC_Board_Left.sch, ADC_Board_Right.brd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]
2015-09-02 Alterações ligeiras nos esquemas eléctricos das placas das ADCs.
    [ADC_Board_Left.brd, ADC_Board_Left.sch, ADC_Board_Right.brd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]
2015-09-02 Mais formatos de imagens das placas das ADCs
2015-09-02 Led board Kicad source files
    [$savepcb.brd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]
2015-09-02 adding led board schematic image file
2015-09-09 Documentação dos pinos de CS das placas das ADCs
    [ADC_Board_Left.brd, ADC_Board_Right.brd]
2015-09-21 100 LEDs mapped
2015-10-13 Protótipo para uma shield para o arduino mega para ligar as placas "ADC_Board"
    [Arduino_Board.brd, Arduino_Board.sch]
2016-03-30 Adicionado ficheiro '.gitignore' a pasta Arduino_Board
2016-03-30 Adicionado programa de teste dos LDRs via ADC_Board
2016-03-30 Adicionado mapa de ligações

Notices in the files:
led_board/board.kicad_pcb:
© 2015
